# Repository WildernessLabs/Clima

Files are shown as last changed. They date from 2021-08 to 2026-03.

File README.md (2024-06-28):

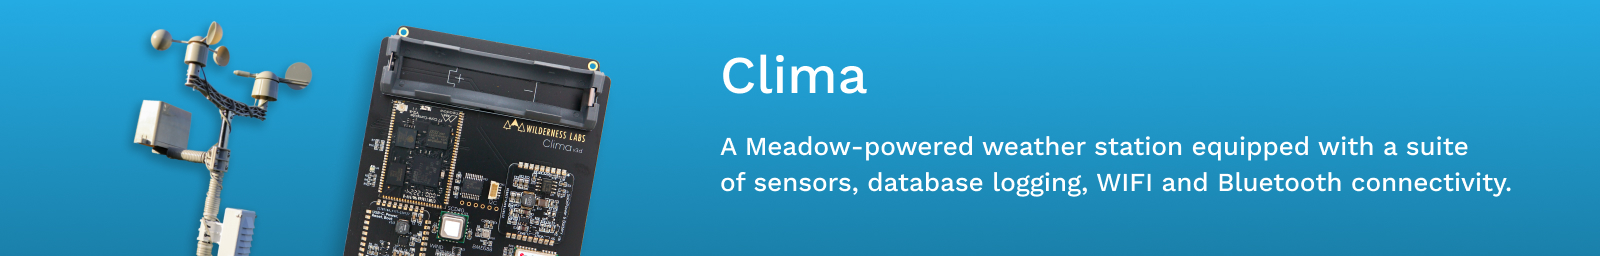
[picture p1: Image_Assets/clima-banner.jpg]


Clima is a solar-powered, custom embedded-IoT solution that tracks climate from a suite of sensors, saves data locally for access via Bluetooth, uses a RESTful Web API, and synchronizes data to the cloud.

## Contents
* [Clima Pro](#clima)
* [Assembly Instructions](#assembly-instructions)
* [Getting Started](#getting-started)
* [Hardware Specifications](#hardware-specifications)
* [Support](#support)

## Clima

With this kit, it includes the complete package of sensors, PCB enclosure and mount to place this outdoors. You'll be able to measure wind speed/direction, rain volume, atmospheric conditions like temperature, pressure, humidity, CO2 levels and GPS Coordinates.

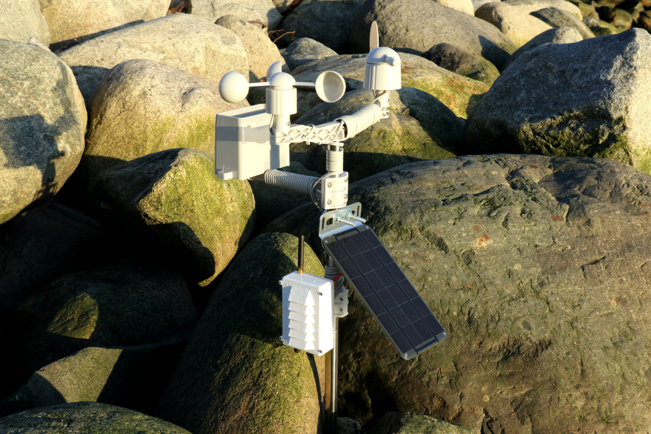
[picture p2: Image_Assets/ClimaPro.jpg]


## Assembly Instructions

A complete kit of Clima.Pro can be found on the [Wilderness Labs Store](https://store.wildernesslabs.co/collections/frontpage/products/clima-weather-station-kit) and the Instructions for assembly can be found [here](/Docs/Clima.Pro/Assembly_Instructions/readme.md).

The store version is 100% kit complete, including the option to upgrade the PCB, Enclosure and Battery only, if you include a previous version of the kit.

You can also source all of the components yourself. For a list of components see the [Clima Pro Bill of Material (BoM)](/Docs/Clima.Pro/Bill_of_Materials.md)

## Getting Started

To simplify the way to use this Meadow-powered reference IoT product, we've created a NuGet package that instantiates and encapsulates the onboard hardware into a `Clima` class.

1. Add the ProjectLab Nuget package your project: 
    - `dotnet add package Meadow.Clima`, or
    - [Meadow.Clima Nuget Package](https://www.nuget.org/packages/Meadow.Clima/)

2. Change the App type on your MeadowApp class to `ClimaAppBase` and initialize Clima's `MainController` passing the `Hardware` and a `INetworkAdapter` such as your WiFi adapter onboard the Meadow Core Compute Module:  

```csharp
public class ClimaApp : ClimaAppBase
{
    public override Task Initialize()
    {
        Resolver.Log.Info($"Initialize...");

        var mainController = new MainController();

        var wifi = Hardware.ComputeModule.NetworkAdapters.Primary<IWiFiNetworkAdapter>();

        mainController.Initialize(
            hardware: Hardware,
            networkAdapter: wifi);
            .
            .
            .
```

3. Run the [Clima_Demo](Source/Clima_Demo/) project that does periodic readings of all its sensors and sends them to [Meadow.Cloud](https://www.meadowcloud.co) if you have a Wilderness Labs account and have provisioned your device.

## Hardware Specifications

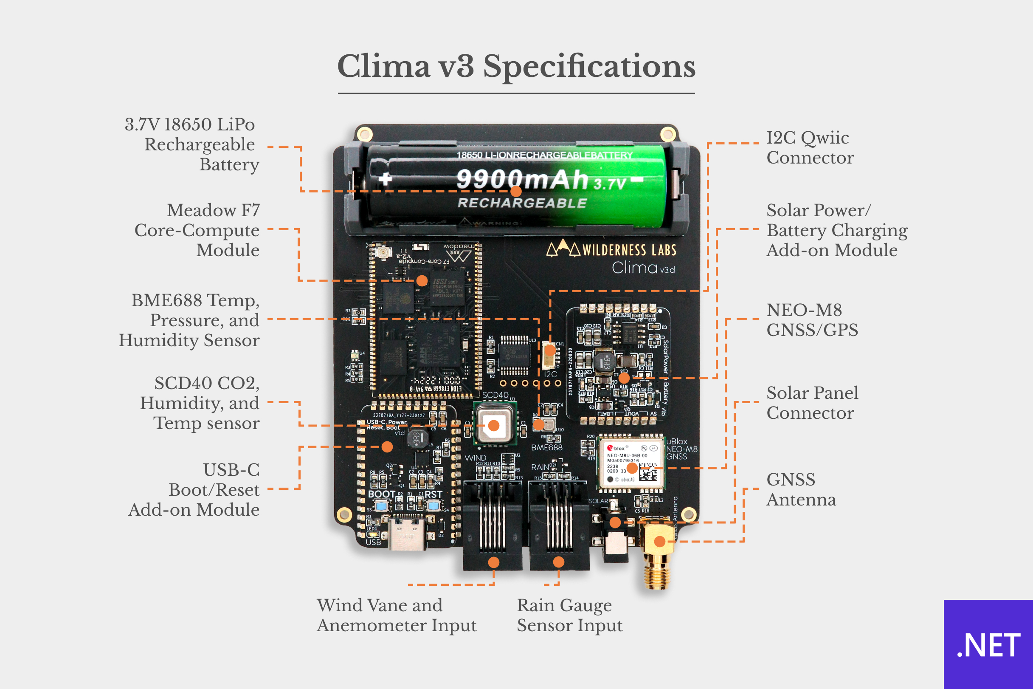
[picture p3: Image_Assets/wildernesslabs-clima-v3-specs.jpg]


You can find the schematics and other design files in the [Hardware_Design folder](Hardware_Design/).

## Support

Having trouble building/running these projects? 
* File an [issue](https://github.com/WildernessLabs/Meadow.Desktop.Samples/issues) with a repro case to investigate, and/or
* Join our [public Slack](http://slackinvite.wildernesslabs.co/), where we have an awesome community helping, sharing and building amazing things using Meadow.

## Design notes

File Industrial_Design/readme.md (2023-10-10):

# Industrial Design

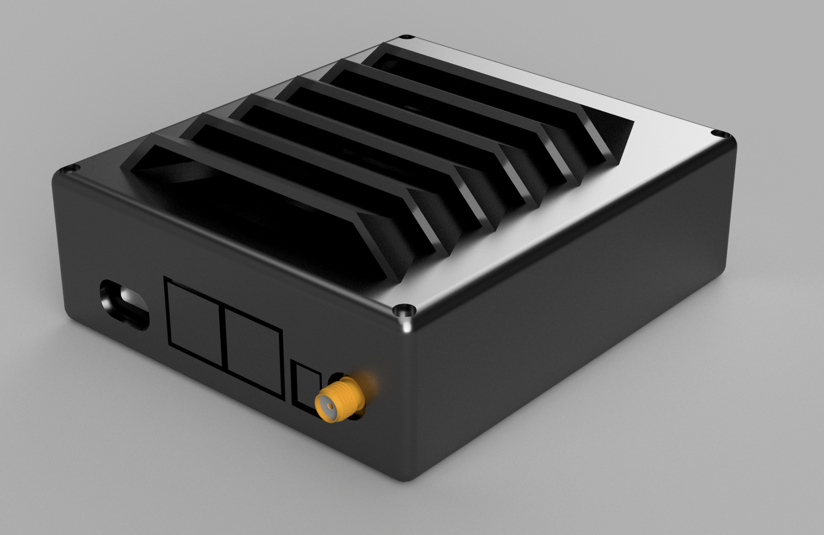
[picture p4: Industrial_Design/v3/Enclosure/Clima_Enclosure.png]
Rendering of the Clima enclosure.


Clima.Pro uses a 3D-Printable enclosure that holds the Meadow board and the custom Clima PCB. 

The enclosure was designed used AutoDesk Fusion 360, and if you want to customize it, you can find the design source in the source folders:
 * [V1](v1/Enclosure/Source)
 * [v3](v3/Enclosure/Source)

The STL files can be found in the `STLs_for_Printing` folder
 * [V1](v1/Enclosure/STLs_for_Printing)
 * [V3](v3/Enclosure/STLs_for_Printing)

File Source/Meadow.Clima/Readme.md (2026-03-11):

# Meadow.Clima

**Library for the Meadow Clima IoT weather station accelerator**

The **Clima** library is included in the **Meadow.Clima** nuget package and is designed for the [Wilderness Labs](www.wildernesslabs.co) Meadow .NET IoT platform.

Clima is a solar-powered, custom embedded-IoT solution that tracks climate from a suite of sensors, saves data locally, and synchronizes telemetry to Meadow.Cloud.

For more information on developing for Meadow, visit [developer.wildernesslabs.co](http://developer.wildernesslabs.co/).

To view all Wilderness Labs open-source projects, including samples, visit [github.com/wildernesslabs](https://github.com/wildernesslabs/).

## Onboard Hardware

| Peripheral | Description |
|---|---|
| NEO-M8 | GNSS/GPS module |
| BME688 | Temperature, pressure, humidity, and gas resistance sensor |
| SCD40 | CO2, humidity, and temperature sensor |
| SwitchingAnemometer | Wind speed sensor |
| WindVane | Wind direction sensor |
| SwitchingRainGauge | Rain accumulation sensor |
| RGB LED | Onboard status indicator |
| Solar input | Solar charging with battery voltage monitoring |

## Installation

You can install the library from within Visual Studio using the NuGet Package Manager or from the command line using the .NET CLI:

`dotnet add package Meadow.Clima`

## Usage

```csharp
public class ClimaApp : ClimaAppBase
{
    public override Task Initialize()
    {
        Resolver.Log.Info("Initialize...");

        var mainController = new MainController();

        var wifi = Hardware.ComputeModule.NetworkAdapters.Primary<IWiFiNetworkAdapter>();

        mainController.Initialize(
            hardware: Hardware,
            networkAdapter: wifi);

        return base.Initialize();
    }

    public override Task Run()
    {
        return base.Run();
    }
}
```

For lower-level hardware access, you can use `ClimaHardwareProvider` directly:

```csharp
public class MeadowApp : App<F7CoreComputeV2>
{
    IClimaHardware clima;

    public override Task Initialize()
    {
        clima = ClimaHardwareProvider.Create();

        if (clima.TemperatureSensor is { } tempSensor)
        {
            tempSensor.Updated += (s, e) =>
                Resolver.Log.Info($"Temperature: {e.New.Celsius:N1}C");
        }

        if (clima.Anemometer is { } anemometer)
        {
            anemometer.Updated += (s, e) =>
                Resolver.Log.Info($"Wind speed: {e.New.KilometersPerHour:N1} km/h");
        }

        if (clima.Gnss is { } gnss)
        {
            gnss.GnssDataReceived += (s, e) =>
                Resolver.Log.Info($"GNSS data received");
        }

        return Task.CompletedTask;
    }

    public override async Task Run()
    {
        if (clima.TemperatureSensor is { } tempSensor)
            tempSensor.StartUpdating(TimeSpan.FromMinutes(1));

        if (clima.Anemometer is { } anemometer)
            anemometer.StartUpdating(TimeSpan.FromSeconds(15));

        if (clima.Gnss is { } gnss)
            gnss.StartUpdating();

        await Task.Delay(Timeout.Infinite);
    }
}
```

## How to Contribute

- **Found a bug?** [Report an issue](https://github.com/WildernessLabs/Meadow_Issues/issues)
- Have a **feature idea or driver request?** [Open a new feature request](https://github.com/WildernessLabs/Meadow_Issues/issues)
- Want to **contribute code?** Fork the [Clima](https://github.com/WildernessLabs/Clima) repository and submit a pull request against the `develop` branch

## Need Help?

If you have questions or need assistance, please join the Wilderness Labs [community on Slack](http://slackinvite.wildernesslabs.co/).

## About Meadow

Meadow is a complete, IoT platform with defense-grade security that runs full .NET applications on embeddable microcontrollers and Linux single-board computers including Raspberry Pi and NVIDIA Jetson.

### Build

Use the full .NET platform and tooling such as Visual Studio and plug-and-play hardware drivers to painlessly build IoT solutions.

### Connect

Utilize native support for WiFi, Ethernet, and Cellular connectivity to send sensor data to the Cloud and remotely control your peripherals.

### Deploy

Instantly deploy and manage your fleet in the cloud for OtA, health-monitoring, logs, command + control, and enterprise backend integrations.

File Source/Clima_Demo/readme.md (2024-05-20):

```mermaid
flowchart TD
%% Nodes
    A("Boot")
    B{"Connect to Cloud"}
    C("Deliver Data")
    D("Shutdown network")
    E("Device Sleep")
    F("Device Wake")
    G("Collect Telemetry")
    H{{"`tick++ % pubcount`"}}

    ne_0("== 0")
    eq_0("!= 0")

%% Edge connections between nodes
    A --> B
    B --> yes --> C
    B --> no --> E
    C --> D
    D --> E
    E -.-> F
    F --> G
    G --> H
    H --> eq_0 --> E
    H --> ne_0 --> B
```

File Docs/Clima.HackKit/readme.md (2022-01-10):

# Clima Hack Kit Circuit

With an LM35 Analog Temperature sensor, a TFT SPI ST7789 display and three push buttons (all included in the Hack Kit), wire your board like the following Fritzing Diagram:

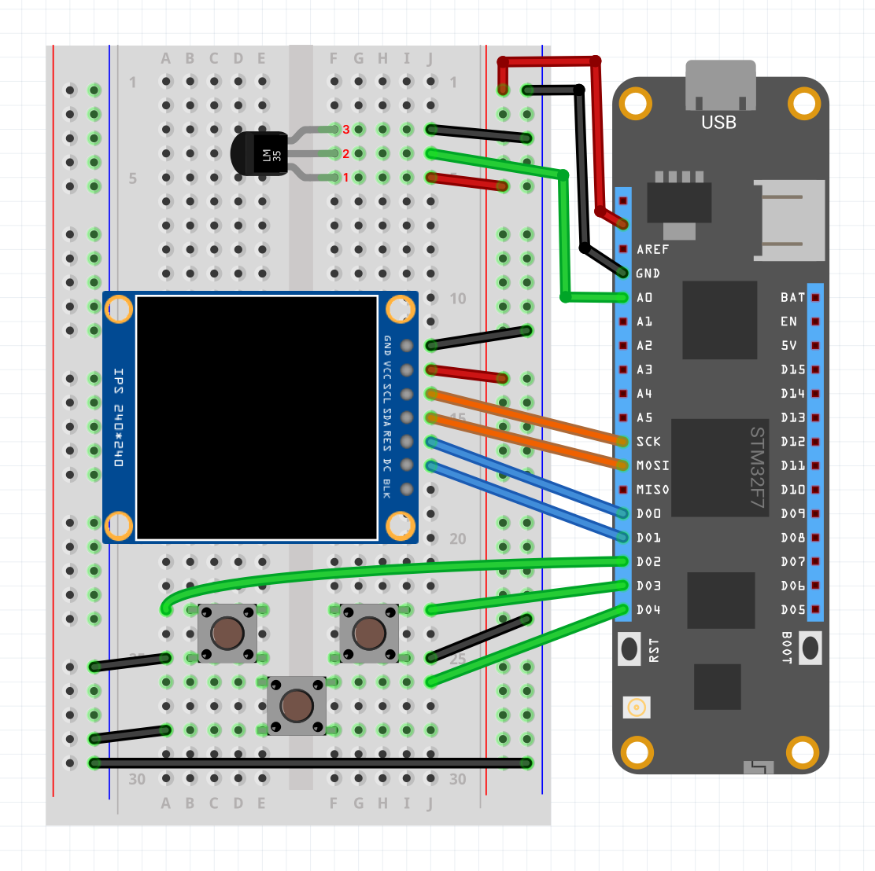
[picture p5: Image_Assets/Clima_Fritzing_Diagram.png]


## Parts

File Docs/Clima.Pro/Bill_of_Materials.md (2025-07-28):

# Clima.Pro Bill of Materials (BoM)

Complete Clima.Pro kits can be purchased at the [Wilderness Labs Store](https://store.wildernesslabs.co/collections/frontpage/products/clima-weather-station-kit), or you can source the components yourself. The Clima.Pro BoM is listed below:

| Qty | Item | Cost/MSRP (approx.) |
|-----|---|---|
| 1 | [Shenzen Fine-Offset Electronics Weather Sensor Kit](https://www.sparkfun.com/products/15901) | $ 79.95 |
| 1 |	Clima PCB (see below) | ~$ 25.00 | 
| 1 | 3d Printed Enclosure and Pipe Mount (see below) | $ 3.00 |
| 1 | [18650 LiIon Battery](https://www.amazon.com/s?k=18650+battery) | $ 5.00 |
| 8 | [M3 Heat Inserts](https://www.amazon.com/gp/product/B087NBYF65) | $ 5.00 |
| 8 | [M3x12 Hex Head Screws](https://www.amazon.com/gp/product/B01LZPZL3W) | $ 5.00 | 
| 4 | [M2x3 Heat-Set Inserts](https://www.amazon.com/gp/product/B07LBRL93N/) | $ 1.00 |
| 8 | [M2x6 bolts (4 for lid, 4 for board)](https://www.amazon.com/Hilitchi-420pcs-Stainless-Socket-Assortment/dp/B014OO5KQG) | $ 1.00 |
| 1 | [3.5 Watt, 6V Solar Panel](https://voltaicsystems.com/3-5-watt-panel/) | $ 30.00 |
| 1 | [Solar Panel Bracket](https://voltaicsystems.com/small-bracket/) | $ 6.00 |
| 1 | [U-Bolt With Mounting Plate, 1/4"-20 Thread Size, 1" Id](https://www.mcmaster.com/catalog/127/1720/) | $ 2.00 |
| 1 | [Antenna - 2dBi SMA Plug](https://octopart.com/ant-2whip2-sma-rf+solutions-87213220?r=sp) | $ 3.50 |
| 1	  | [SMA to uFL/u.FL/IPX/IPEX RF Adapter Cable](https://www.adafruit.com/product/851) | $ 4.00 |

## 3D Printed Enclosure

The enclosure can be 3D printed, but should be printed using PETG or some other UV-Resistant material. PLA will degrade quickly in the sun. Additionally, it should be a light color such as white to avoid passive solar radiation absorption which will interfere with the temperature and humidity readings. We use the [Duramic 3D Silk White](https://www.amazon.com/gp/product/B07TRPQ4MN) filament.

If you're printing the enclosure yourself, you'll also need a [soldering iron](https://www.amazon.com/dp/B00B3SG6UQ) and [heat-set insert tips](https://www.amazon.com/dp/B08B17VQLD) to install the heat-set inserts.

All of the enclosure files can be found in the [/Industrial_Design folder](/Industrial_Design/).

## Clima.Pro PCB

The Clima.Pro PCB was created in EasyEDA, and the source files as well as component BoM can be found on [OSHW Lab](https://oshwlab.com/bryan_6020/wilderness-labs-clima).

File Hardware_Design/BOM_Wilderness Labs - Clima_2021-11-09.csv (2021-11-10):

ID | Name | Designator | Footprint | Quantity | Manufacturer Part | Manufacturer | Supplier | Supplier Part | Price
1 | 0.1u | C1,C2,C3 | C0603 | 3 | CC0603KRX7R9BB103 | Yageo
2 | 47pF | C4 | C0603 | 1 | CC0603JRNPO9BN470 | Yageo
3 | BAS70FILM | D1 | SOT23-3 | 1 | BAS70FILM | STMicroelectronics | LCSC | C233387 | 0.133
4 | BAS70-04FILM | D2 | SOT-23-3_L2.9-W1.3-P1.90-LS2.4-BR | 1 | BAS70-04FILM | STMicroelectronics | LCSC | C283251 | 1.046
5 | NEO-M8U-0 | IC1 | NEO-M8U | 1
6 | PJ-002AH-SMT-TR | J2 | CUI_PJ-002AH-SMT-TR | 1
7 | 1kΩ | L1 | L0402 | 1 | BLM15HD102SN1D | MuRata | LCSC | C21516 | 0.007
8 | 4.7kΩ | R1,R2,R13 | R0603 | 3 | RC0603FR-074K7L | Yageo
9 | 220 | R3,R4 | R0603 | 2 | RC0603FR-07220RL | Yageo
10 | 10k | R5,R6,R8 | R0603 | 3 | RC0603FR-0710KL | Yageo
11 | 10 | R7 | R0603 | 1 | RC0603FR-0710RL | Yageo
12 | 1k | R9,R10,R11,R12,R14,R15,R16 | R0603 | 7 | RC0603FR-071KL | Yageo
13 | 680 | R17 | R0603 | 1 | RC0603FR-07680RL | Yageo
14 | 1909763-1 | RF1 | ANT-SMD_1909763-1 | 1 | 1909763-1 | TE Connectivity | LCSC | C392444 | 0.208
15 | 5555165-1 | RJ1-WIND,RJ2-RAIN | RJ11-TH_6P-P2.54-S2.54_L18.3-W13.4-EH10.2 | 2 | 5555165-1 | TE Connectivity | LCSC | C305981 | 0.725
16 | Meadow F7 Micro Dev Board | U1 | MEADOWF7MICRO_HEADERS_ONLY | 1 | MEDF7DEV | Wilderness Labs | Mouser | 977-MEADOWF7MICRO
17 | BAV99DWQ-7-F | U2 | SOT363 (NO POLARITY) | 1 | BAV99DWQ | Diodes Incorporated | Digi-Key | BAV99DWQ-7-FDITR-ND
18 | 2200mAh Battery Holder | U3 | 2200MAH_BATTERY_HOLDER | 1
19 | BME680 | U4 | LGA-8_L3.0-W3.0-P0.80-TR | 1 | BME680 | Bosch Sensortec | LCSC | C125972 | 16.526

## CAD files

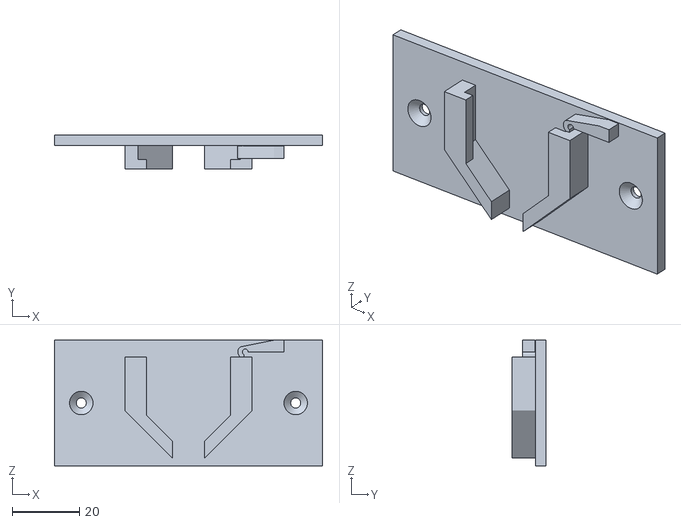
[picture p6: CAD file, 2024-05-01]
Industrial_Design/v4/clima4-cleat-f.stl
80.0 x 10.0 x 37.5

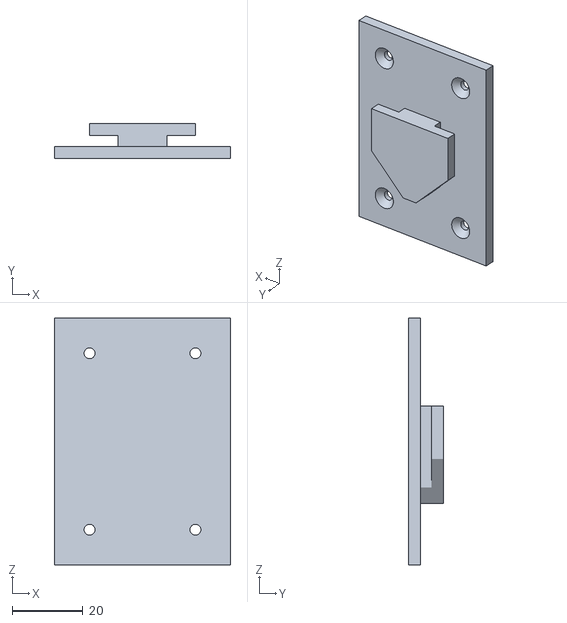
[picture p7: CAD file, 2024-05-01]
Industrial_Design/v4/clima4-cleat-m.stl
50.0 x 10.0 x 70.0

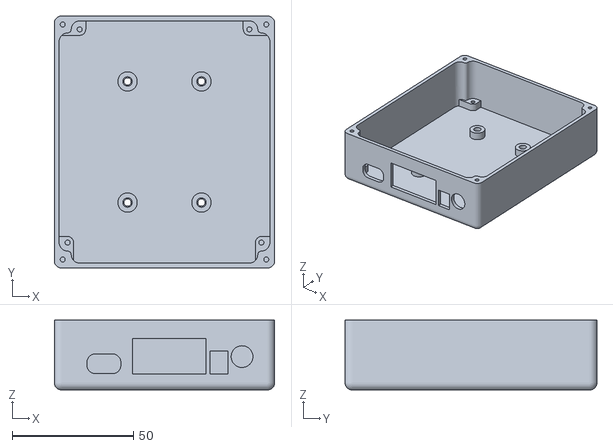
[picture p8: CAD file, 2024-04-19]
Industrial_Design/v4/Clima4_Enclosure_Bottom.stl
91.0 x 104.0 x 28.9

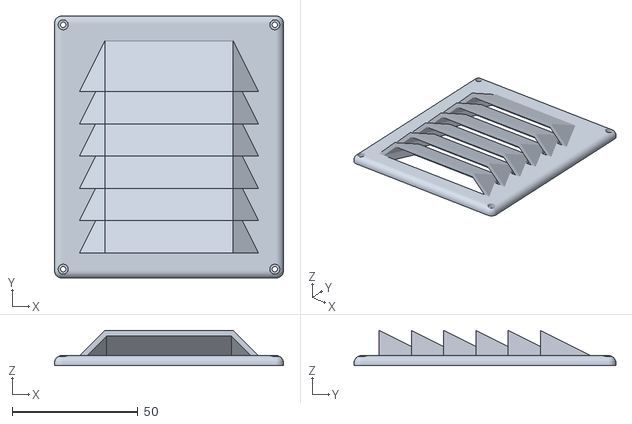
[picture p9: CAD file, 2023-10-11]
Industrial_Design/v4/Clima4_Enclosure_Top.stl
91.0 x 104.0 x 14.0

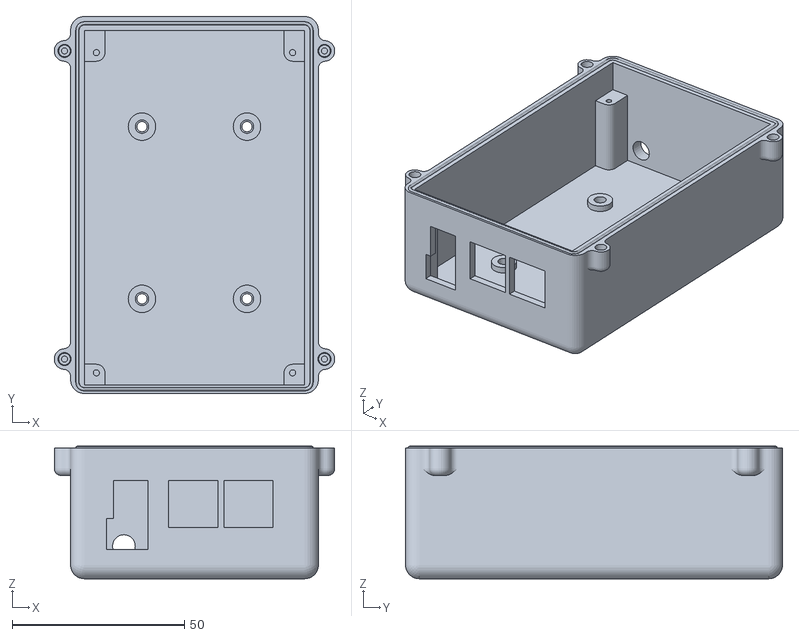
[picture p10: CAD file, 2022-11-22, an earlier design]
Industrial_Design/v1/Enclosure/STLs_for_Printing/Clima_Enclosure_Bottom.stl
81.5 x 109.5 x 38.5

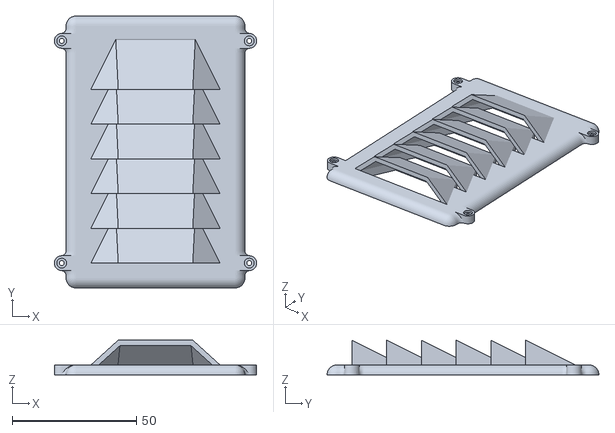
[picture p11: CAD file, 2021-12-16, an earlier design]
Industrial_Design/v1/Enclosure/STLs_for_Printing/Clima_Enclosure_Top.stl
81.5 x 109.5 x 14.0

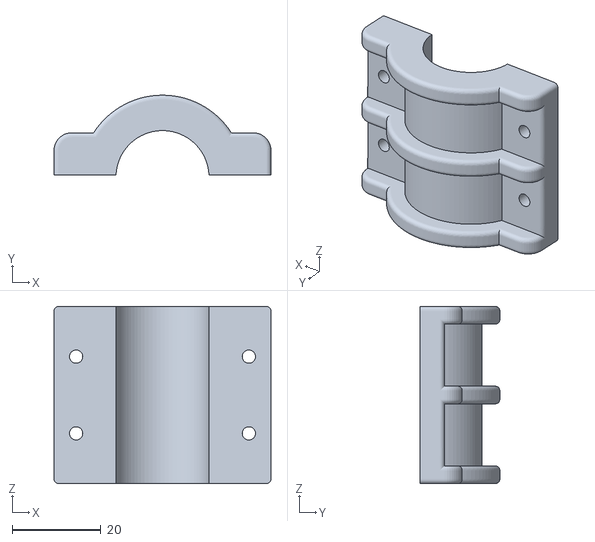
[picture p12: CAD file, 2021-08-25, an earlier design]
Industrial_Design/v3/Enclosure/STLs_for_Printing/Pipe_Mount_Clamp_Closure_Side.stl
49.0 x 18.0 x 40.0

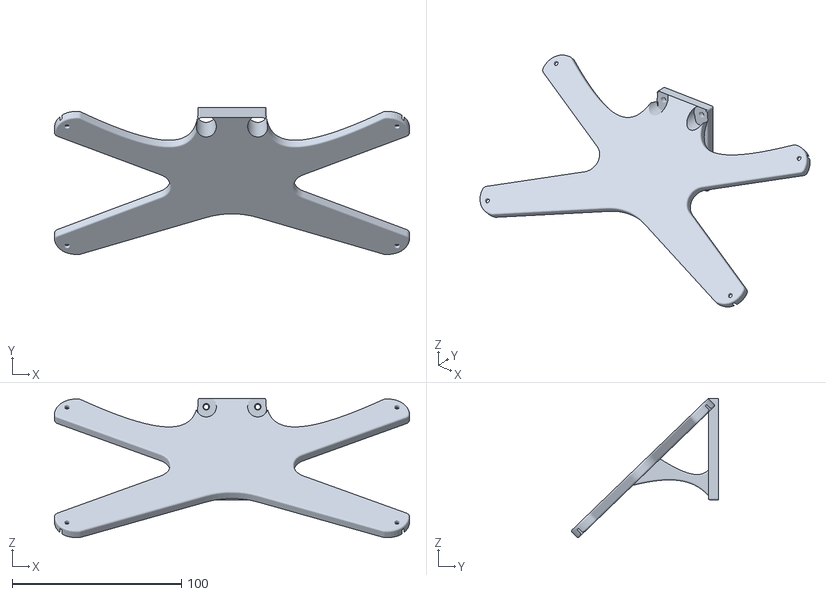
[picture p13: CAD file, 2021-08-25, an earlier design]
Industrial_Design/v1/Enclosure/STLs_for_Printing/Pipe_Mount_Solar_Adapter.stl
210.0 x 86.9 x 82.4

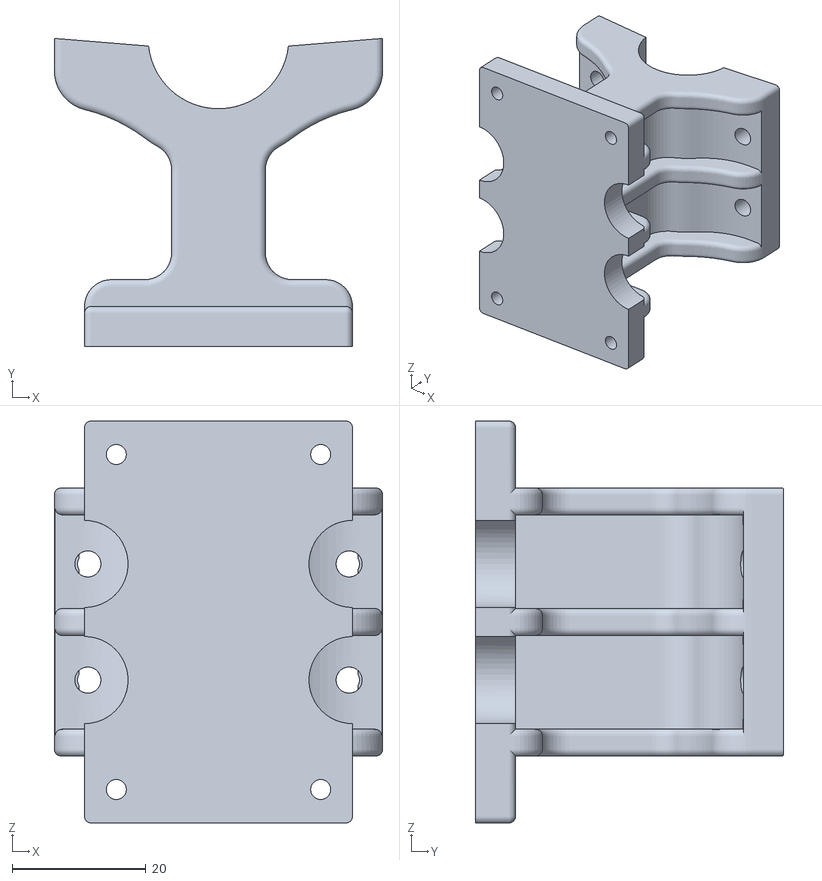
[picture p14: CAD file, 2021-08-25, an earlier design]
Industrial_Design/v3/Enclosure/STLs_for_Printing/Pipe_Mount_Enclosure_Side.stl
49.0 x 46.0 x 60.0

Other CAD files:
Industrial_Design/v3/Enclosure/STLs_for_Printing/CL_Enclosure_Bottom.stl
Industrial_Design/v1/Enclosure/Source/Clima.Pro Enclosure.f3d
Industrial_Design/v1/Enclosure/Source/Clima_Clamp.f3d
Industrial_Design/v3/Enclosure/Source/Clima v3 Enclosure.f3z
Industrial_Design/v3/Enclosure/Source/Clima_Clamp.f3d

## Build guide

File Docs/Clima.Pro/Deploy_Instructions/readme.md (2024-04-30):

## Clima.Pro Application Deployment

### Step 1. - Prepare Dev Environment

 * **Download and install [Visual Studio](https://visualstudio.microsoft.com/) or [Visual Studio Code](https://code.visualstudio.com/)** - For either Windows or macOS. Community edition will work fine.

 * **Follow the [Meadow.OS Deployment Guide](http://developer.wildernesslabs.co/Meadow/Getting_Started/Deploying_Meadow/)**:
   * The above guide should show you how to install `Meadow.CLI`
   * Walk your through out to download the latest Meadow.OS and flash it to the Clima Meadow board.

 * **Follow the [`Hello, Meadow` Guide](http://developer.wildernesslabs.co/Meadow/Getting_Started/Hello_World/)**:
   * The above guid should show  you to Install the Visual Studio and VSCode Extension(s) for Meadow.

### Expected Development version stack (RC-1)
At this point, you should have the following versions on your development machine
* Meadow.CLI - `v2.x`
* Visual Studio
  * MacOS - `v1.9.x`
  * Windows - `v1.9.x`
* VS Code - `v1.9.x`

* Meadow

And if you run this command line: `meadow device info`, you should see something similar to:
  ```
  Meadow by Wilderness Labs
  Board Information 
      Model: F7Micro
      Hardware version: F7CoreComputeV2
      Device name: MeadowF7

  Hardware Information 
      Processor type: STM32F777IIK6
      ID: [Specific ID for your Meadow]
      Serial number: [Specific Serial No. for your Meadow]
      Coprocessor type: ESP32
      MAC Address - 
    WiFi: [Specific Mac Address for your Meadow]

  Firmware Versions 
      OS: 1.10.0.2
      Runtime: 1.10.0.2
      Coprocessor: 1.10.0.1
      Protocol: 8
  ```

### Step 2. - Deploy the Clima App

 **Clone the Clima Repo**:
 
 [Clone](https://docs.github.com/en/desktop/contributing-and-collaborating-using-github-desktop/adding-and-cloning-repositories/cloning-and-forking-repositories-from-github-d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) the [Clima(this) repository](https://github.com/wildernesslabs/Clima) locally.

 **Open the Clima VS Solution**:

 With either Visual Studio or VSCode running, navigate to the `source` folder and open the `Meadow.Clima.sln`. 

 **Add WiFi Credentials**:
 
 Edit the `secrets.cs` file to have the correct credentials for the WiFi your Clima will connect to.

 **Deploy the MeadowClimaProKit App**

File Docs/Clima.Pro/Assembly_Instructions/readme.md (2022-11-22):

## Clima.Pro Assembly Instructions



* **[Part 1 - 3D Printed Enclosure Assembly](Enclosure_Assembly/readme.md)** - Skip this step unless you're printing at home.
* **[Part 2 - Electronics Installation](Electronics_Installation/readme.md)** - Installing the PCB, antenna, etc., into the enclosure.
* **[Part 3 - Sensor Assembly](Weather_Sensors/readme.md)** - Assembling the weather gauges and pole.
* **[Part 4 - Enclosure Mounting](Enclosure_Mounting/readme.md)** - Mounting the enclosure to the sensor pole.
* **[Part 5 - Solar Panel Installation](Solar_Panel_Installation/readme.md)** - Installing the solar panel.

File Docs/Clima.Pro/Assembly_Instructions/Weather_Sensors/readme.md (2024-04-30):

# Weather Sensors Assembly

To assemble the whole Clima kit with all it's sensors, you'll need the set of 3 long screws with it's bolts, and 2 smaller screws. They should be in a little zip lock bag like this:

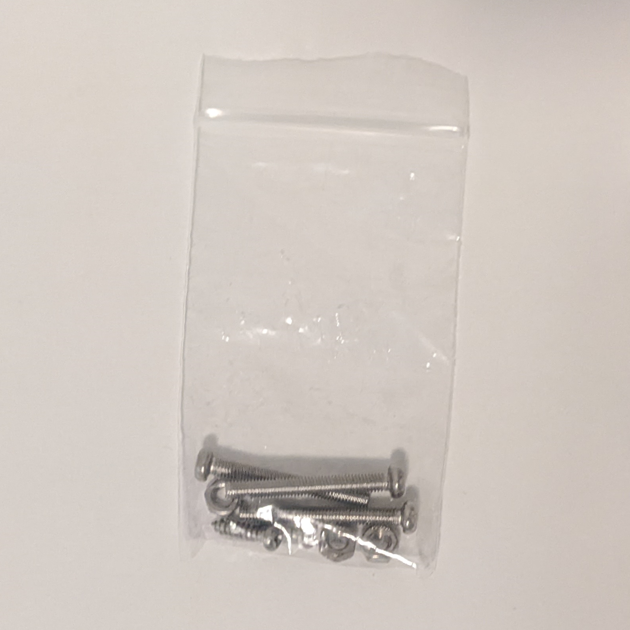
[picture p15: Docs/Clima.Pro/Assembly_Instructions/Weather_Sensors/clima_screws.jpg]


## Assembling

Start by connecting the two steel tubes together like so:



Next, one of the tube ends has a small rounded gap and a hole right below it. In that end, place the sensor support for the wind vane and anemometer. Use one of the long screws and bolts to fix the support to the tube.



On the right end of the support piece you can put the anemometer. It has three possible positions to connect it to the base, keep rotating it until you see the the hole to insert another long screw and bolt to secure it to the support. You can thread the 

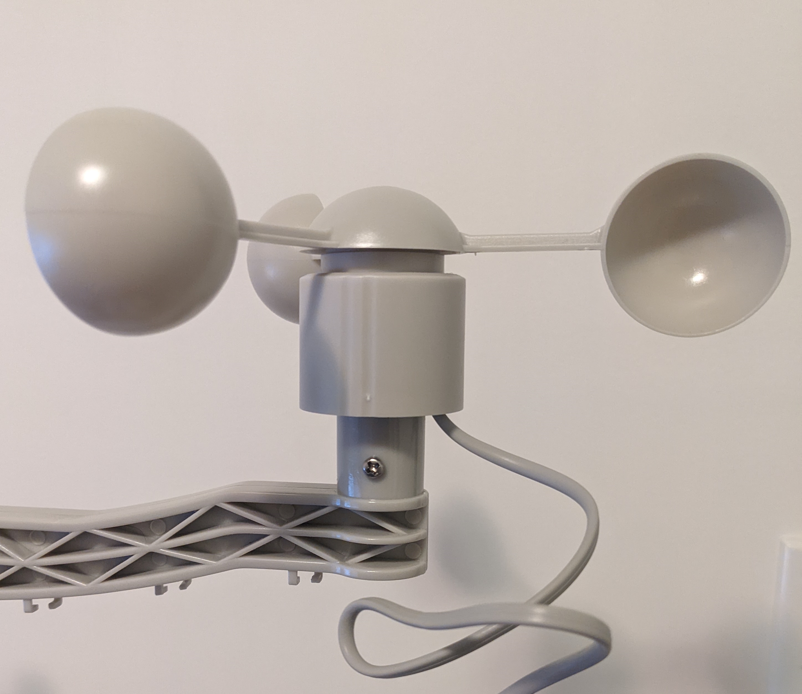
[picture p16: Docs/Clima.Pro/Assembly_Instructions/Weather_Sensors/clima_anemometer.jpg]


On the left side of the support you can place the wind vane. Like we did with the anemometer, make sure to position it correctly to use the third and final screw and bolt to secure the sensor to the support.



Take the short cable from the anemometer and carefully feed/clip it through the provided cable tidies until it reaches the wind vane.

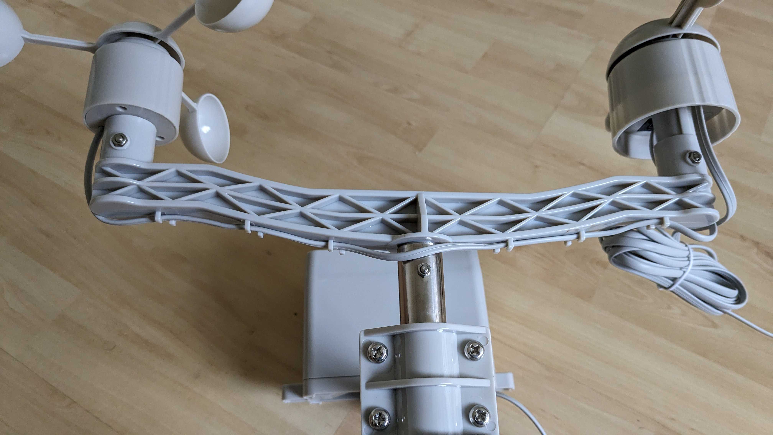
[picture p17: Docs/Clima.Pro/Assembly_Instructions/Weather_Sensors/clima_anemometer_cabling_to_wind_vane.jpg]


Under the wind vane you can see a small connection port. Connect the end of the anemometer into the wind vane port underneath.

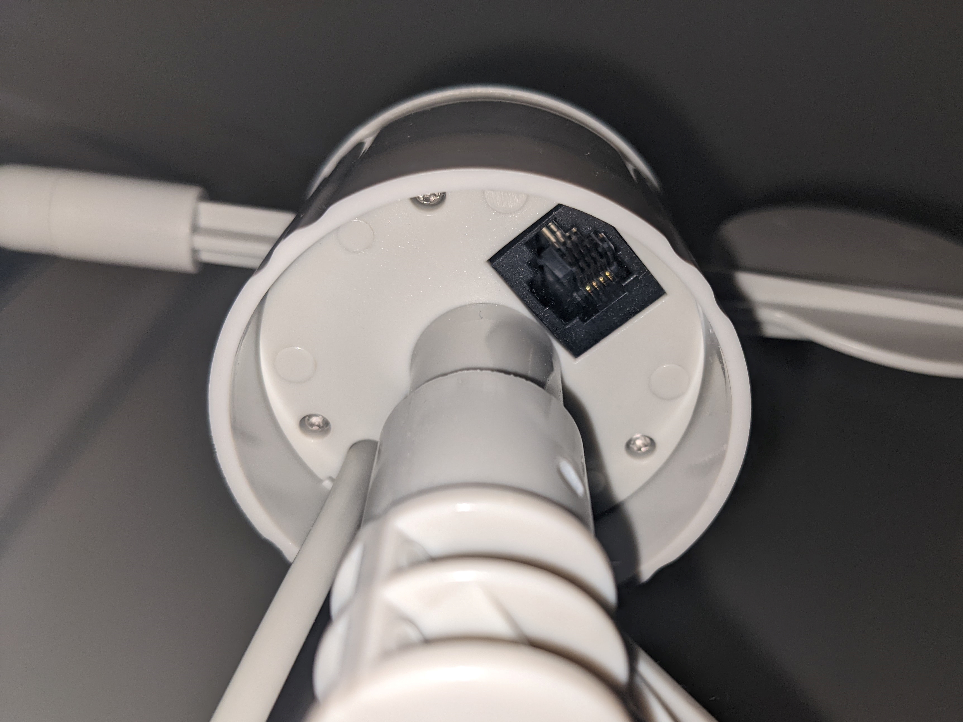
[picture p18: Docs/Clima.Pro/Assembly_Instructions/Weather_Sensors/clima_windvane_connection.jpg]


At this point, you should have something like this:

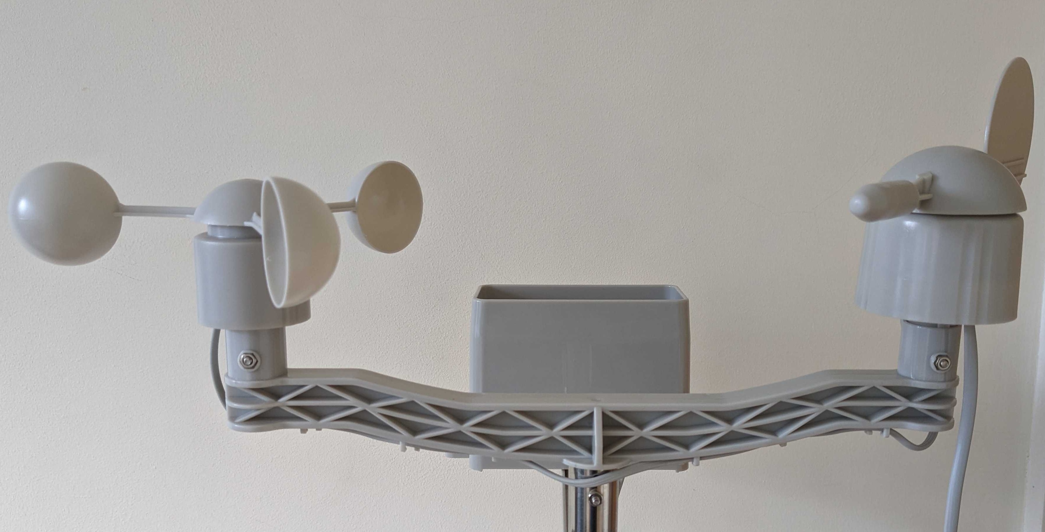
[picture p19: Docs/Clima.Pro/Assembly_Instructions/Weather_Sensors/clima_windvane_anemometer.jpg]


About an inch/2.54cm below the tube end, where the support piece is, use the rain meter support piece and secure it onto the tube, making sure it is perpendicular to the other two sensors.

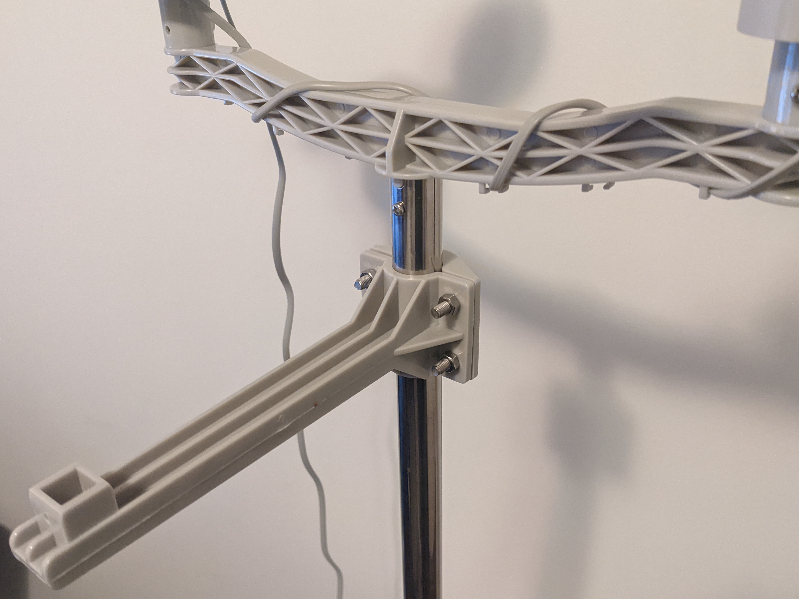
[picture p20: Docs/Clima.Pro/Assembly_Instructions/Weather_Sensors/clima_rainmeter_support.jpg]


Take the rain meter and place it on the support piece and secure it with the last two small screws: one goes in the bottom and the other on one of the sides: 

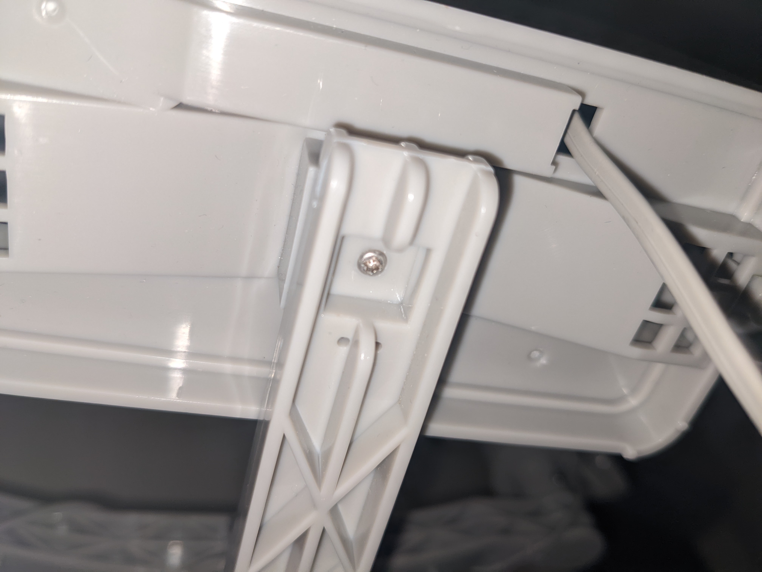
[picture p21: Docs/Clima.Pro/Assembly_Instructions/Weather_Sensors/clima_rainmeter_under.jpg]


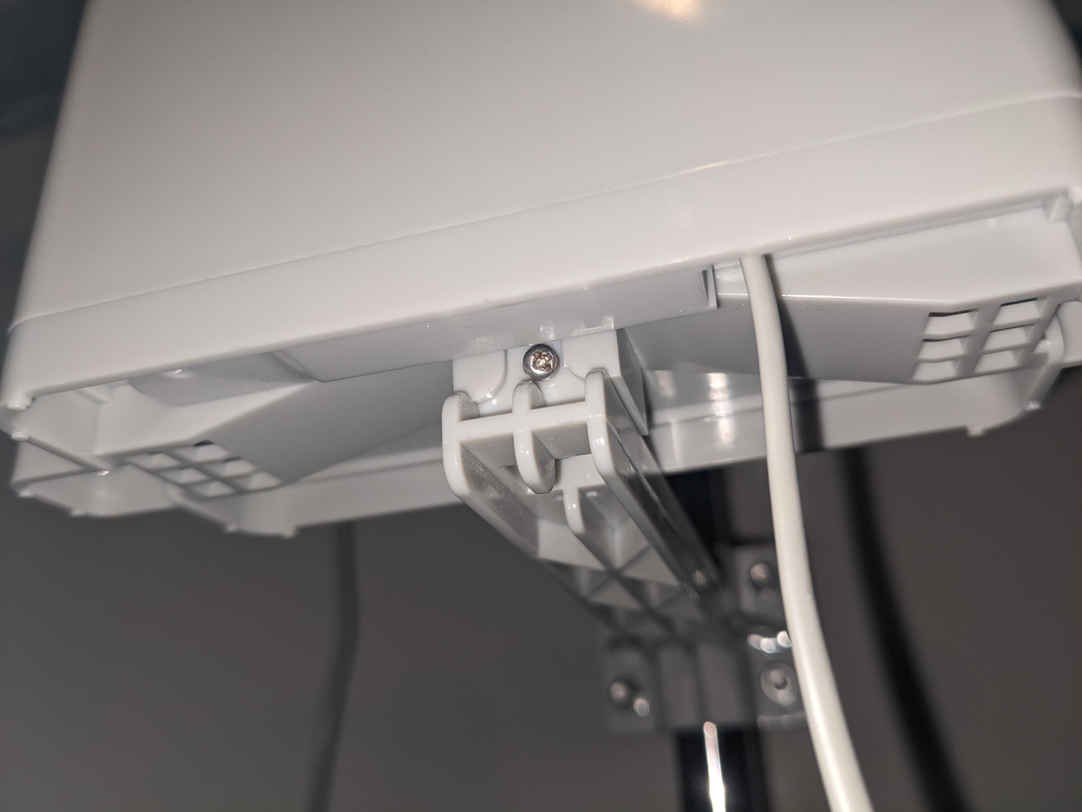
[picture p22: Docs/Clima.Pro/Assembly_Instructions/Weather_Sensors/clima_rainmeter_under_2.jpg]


About one inch/2.54cm above where the 2 steel tubes connect, mount the Clima Meadow module onto the tube.

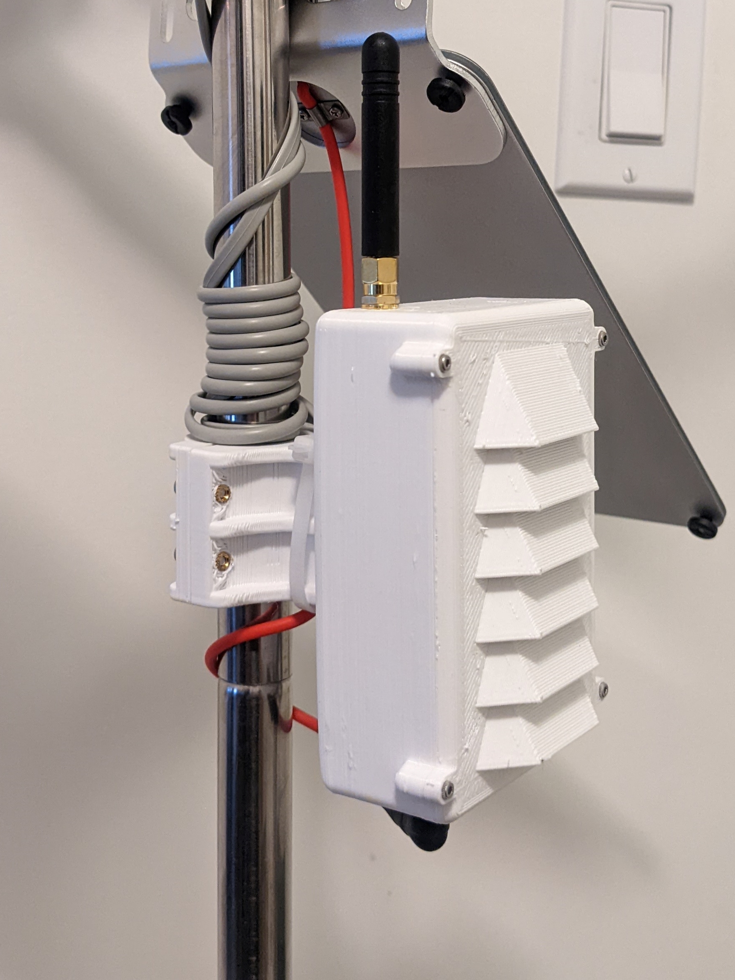
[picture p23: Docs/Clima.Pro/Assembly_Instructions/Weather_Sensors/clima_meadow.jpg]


Now you can connect the rain meter sensor in the middle port and the wind sensor on the other connector available. The round port is used for the solar panel. 

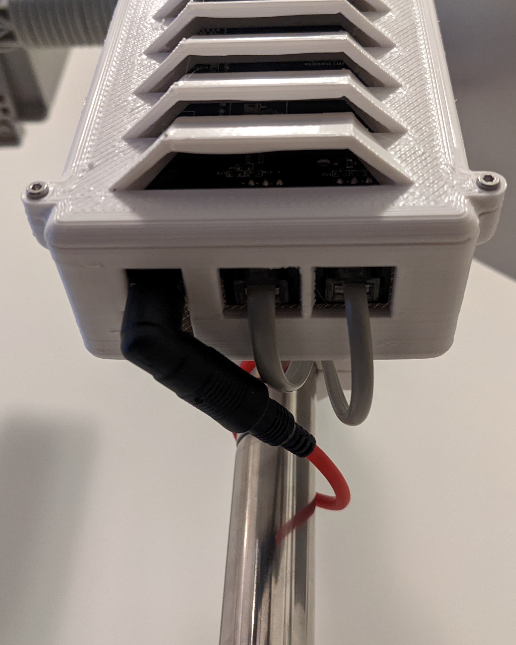
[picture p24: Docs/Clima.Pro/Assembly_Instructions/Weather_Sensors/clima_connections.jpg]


Additionally, you can tidy the cable of the wind sensors by looping it around its support piece and/or tubes, making your way to the Meadow module.



You can do the same with the rain meter sensor's cable, looping it around its support piece, making your way to the Meadow enclosure.

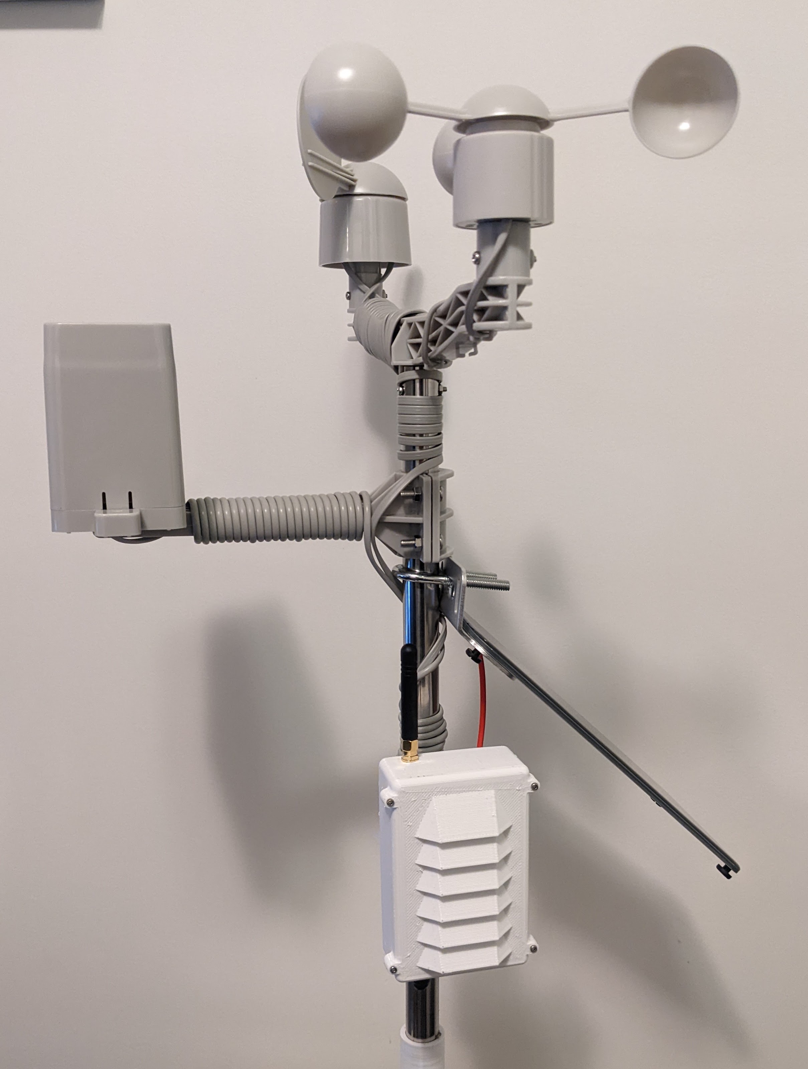
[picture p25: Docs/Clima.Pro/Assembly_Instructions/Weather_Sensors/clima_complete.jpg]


## [Next - Enclosure Assembly](../Enclosure_Assembly/readme.md)

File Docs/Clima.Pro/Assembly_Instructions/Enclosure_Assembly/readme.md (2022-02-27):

# Clima.Pro 3D Printed Enclosure Assembly

If you've ordered the enclosure from the Wilderness Labs store, it already comes assembled with the heat-set inserts in it, so you can skip this step and go directly to [Electronics Installation instructions](../Electronics_Installation/readme.md).

However, if you're 3D printing at home, you'll need to follow the instructions below:

## Post-process 3D Print

Stringing and burrs are a by-product of printing with PETG and are mostly cosmetic, but can easily be cleaned off with a box-cutter knife, razor blade, or similar.

## Install M3 Heat-Set Inserts into Enclosure Body

Install a heat-set insert tool into your soldering iron, plug it in and turn it on. After a couple of minutes it should be hot enough. Place an M3 heat-set insert onto the end of the tool, being careful not to touch the hot tip:



Then, while holding the enclosure, guide the insert into one of the holes until it's just flush with the top of the hole:



Repeat this for all four heat set inserts on the main enclosure body.

## Plunge Excess Plastic from Heat-Set Inserts

Install an M3 bolt through the M3 insert from the inside of the enclosure, to push any plastic that might have melted into the insert:



Screw the bolt far enough that it pokes out the other side of the insert and pushes out the plastic:



Remove the bolt and repeat for the remaining M3 inserts.

Once all four have been plungd, using a knife, trim the excess plastic:



## Install the M3 Heat-Set Inserts into the Enclosure Mount

Using the same method, install (4), M3 inserts into the enclosure mount from the backside, and then push excess plastic out with a bolt and trim:



## Install the M2 Heat-Set Inserts into the Enclosure Body

Finally, install the M2 heat-set inserts for the lid into the enclosure body:



## [Next - Electronics Installation](../Electronics_Installation/readme.md)

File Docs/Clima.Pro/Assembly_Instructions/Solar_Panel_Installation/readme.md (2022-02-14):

# Solar Panel Installation

## Solar Panel Mount

Using the U-bolt bracket, attach the solar panel mount to the pole:

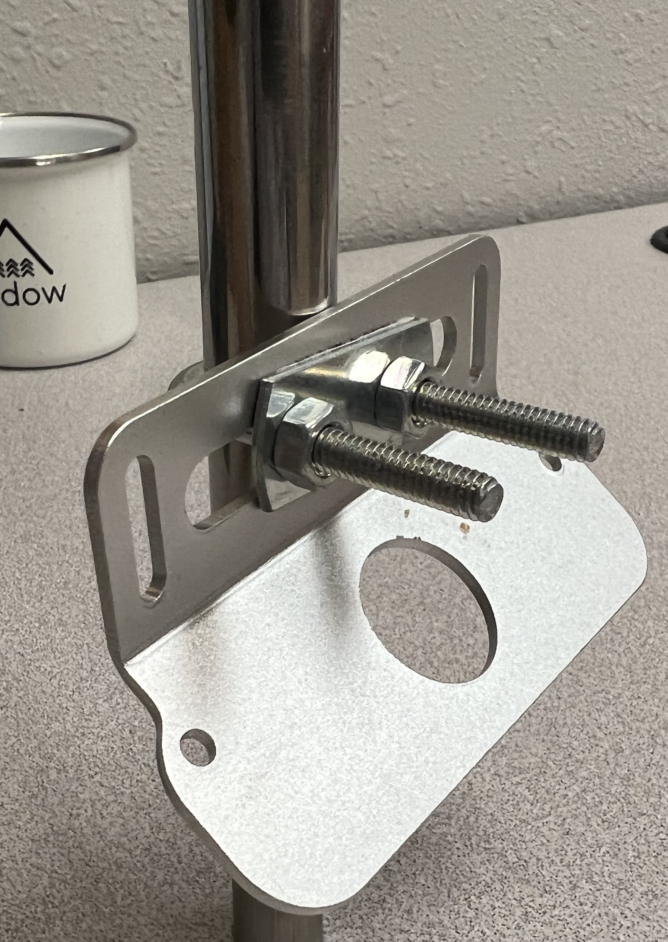
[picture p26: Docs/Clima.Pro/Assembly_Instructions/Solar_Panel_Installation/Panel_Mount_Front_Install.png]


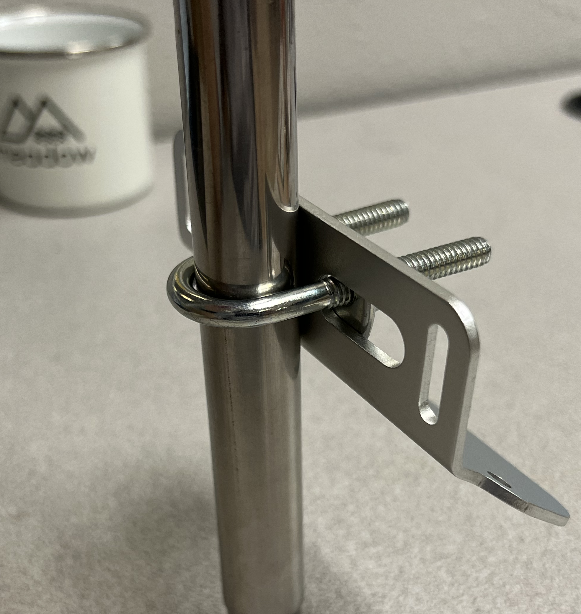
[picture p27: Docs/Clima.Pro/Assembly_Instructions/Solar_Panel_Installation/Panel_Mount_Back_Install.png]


## Install Panel

Using the plastic nuts on the solar panel, attach it to the solar panel bracket mount. Make sure to pull the solar panel power cable through the bracket hole:

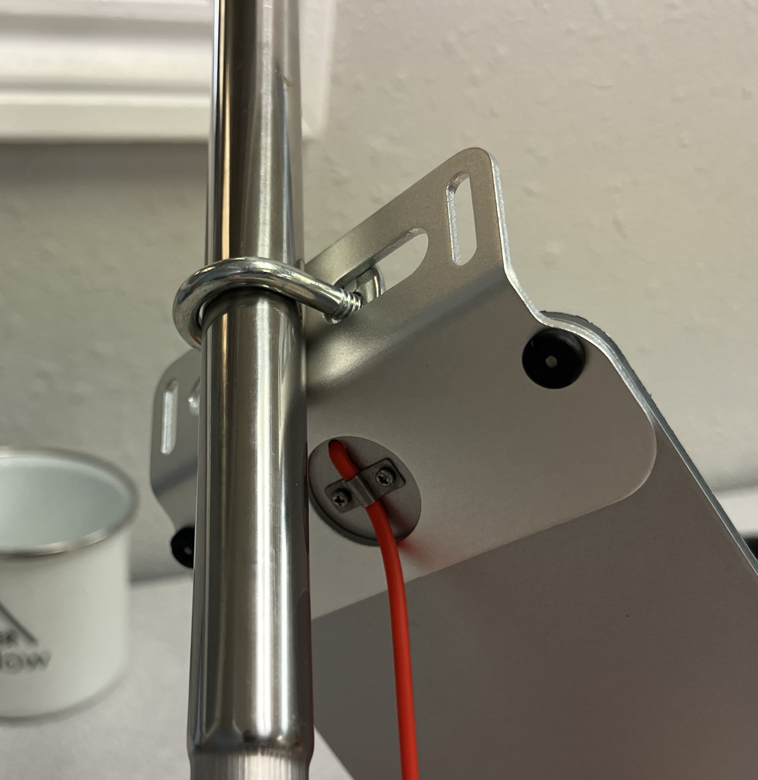
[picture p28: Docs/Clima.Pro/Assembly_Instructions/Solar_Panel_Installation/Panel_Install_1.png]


## [Next - Deploy the Clima App](/Docs/Clima.Pro/Deploy_Instructions/)

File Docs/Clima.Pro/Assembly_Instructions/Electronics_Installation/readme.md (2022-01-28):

# Clima.Pro Electronics Installation

## Install the Antenna Cable and Mount

Unscrew the antenna mount and place it through the hole in the enclosure with the threads up, as shown below. Use the lock-washer on top and the tooth-washer on the bottom:



The antenna mount should fit snuggly, you may need to screw it into place for it to fit.

## Install Battery

Install the 18650 LiIon battery into the holder, paying attention to the polarity. If there is a piece of tape on the battery, remove it:



## Attach Antenna Cable to Meadow

Attach the µFL connector to the Meadow external antenna connector as illustrated below:



## Install the PCB

Using (4) M2x6 screws, install the assembled PCB:



## Install Cover

Using the remaining (4) M2x6 screws, install the cover:



## [Next - Mount the Enclosure](../Enclosure_Mounting/readme.md)

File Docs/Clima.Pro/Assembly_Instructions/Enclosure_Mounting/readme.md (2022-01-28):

# Enclosure Mounting



## [Next - Solar Panel Installation](../Solar_Panel_Installation/readme.md)

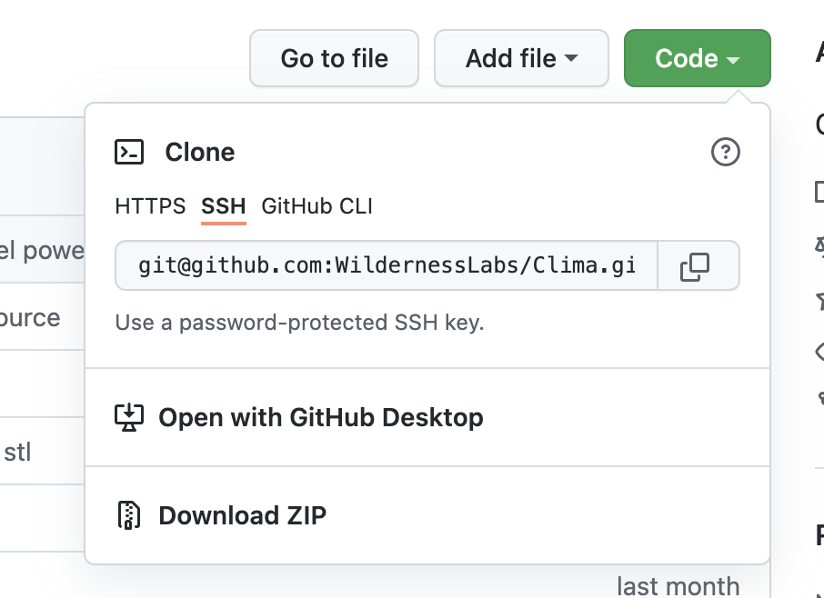
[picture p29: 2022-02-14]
Docs/Clima.Pro/Deploy_Instructions/GitHub_Clone.png

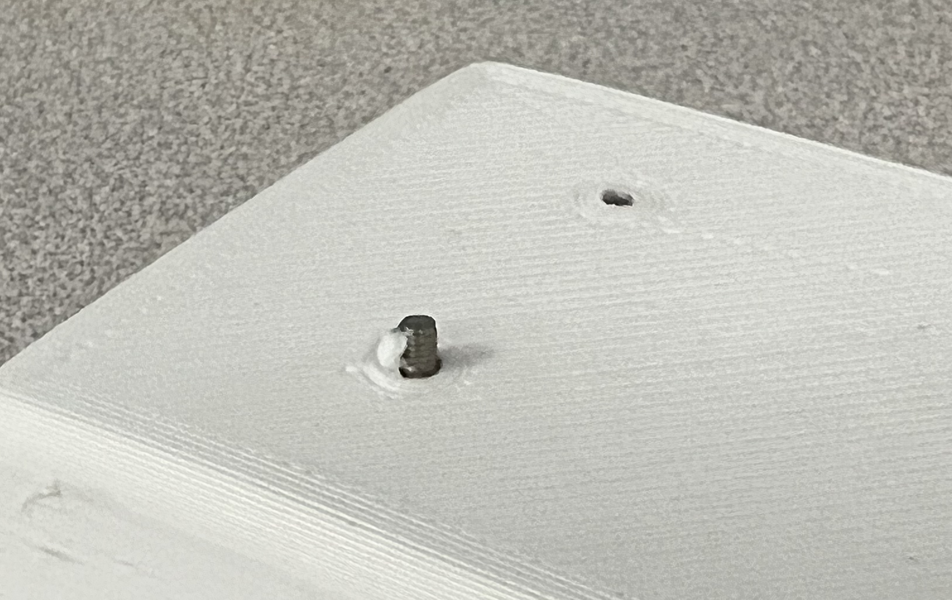
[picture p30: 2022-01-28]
Docs/Clima.Pro/Assembly_Instructions/Enclosure_Assembly/M3_Plunge_Outside.png

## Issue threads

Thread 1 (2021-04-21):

meadow.core not found in local repository (also Meadow.Foundation not found when present)

houstonhaynes, 2021-04-21:
Looks like the Clima project has a dependency on Meadow.Core.

`PS C:\repo\Clima\Source\Clima> dotnet restore Clima.sln
C:\Program Files\dotnet\sdk\5.0.200-preview.21079.7\NuGet.targets(290,5): error MSB3202: The project file "C:\repo\Meadow.Core\source\Meadow.Units\Meadow.Units.csproj" was not found. [C:\repo\Clima\Source\Clima\Clima.sln]`

I'm also seeing this error which I assume is because the restore is failing.

'C:\repo\Meadow.Foundation\Source\Meadow.Foundation.Peripherals\Sensors.Weather.WindVane\Driver\Sensors.Weather.WindVane\Sensors.Weather.WindVane.csproj'. If you are using Visual Studio, this may be because the project is unloaded or not part of the current solution so run a restore from the command-line. Otherwise, the project file may be invalid or missing targets required for restore.	WilderenessLabs.Clima.Meadow.Pro.HardwareDiagnostics	C:\repo\Clima\Source\Clima\WilderenessLabs.Clima.Meadow.Pro.HardwareDiagnostics\WilderenessLabs.Clima.Meadow.Pro.HardwareDiagnostics.csproj'

Is there a place where I can get Meadow.Core? I can't seem to lay my eyes on it here in your public repo.

houstonhaynes, 2021-04-21:
Weird I pulled the local .Core project references and it seemed to use the nuget packages.

Closed 2021-04-21.

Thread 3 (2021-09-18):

Add rain sensor logic

adrianstevens, 2021-09-18:

adrianstevens, 2022-03-08:
Complete - closing issue

Closed 2022-03-08.

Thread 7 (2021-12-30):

Send Data From Meadow to an ASP .NET Server via WiFi Out of Date

JonathanBuchner, 2021-12-30:
For my first practice project I chose the sample project _Send Data From Meadow to an ASP .NET Server via WiFi_ after the Hello, LED project.  The linked directions were not updated and I was unable to follow the directions on the site.  I went to the sample project GitHub and looked at the updates.

Recommendation to add section or badge for _out of date_ or _previous version_ labs to alert users for incorrect lab instructions.  This label is important especially for users doing their first time project.

doingnz, 2025-01-19:
It's really old? Is it still relevant?

@ctacke should this issue be moved to the samples repository as it's not Clima specific.

doingnz, 2025-02-15:
@jorgedevs, @bryancostanich is this issue for December 2021 still relevant? should it be closed or moved to samples? Is it Clima specific or more general to all Meadow samples?

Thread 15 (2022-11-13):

Add RGB LED to Clima Pro's PCB as a status indicator

jorgedevs, 2022-11-13:
It's hard to tell if Meadow App is running properly once deployed out in the field with no visible indication that the app is running, or the system is turned on.

bryancostanich, 2023-08-28:
Added in v3.

Closed 2023-08-28.

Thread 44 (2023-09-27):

[Clima.HackKit] Fritzing diagram LM35 error

patridge, 2023-09-27:
https://github.com/WildernessLabs/Clima/blob/main/Image_Assets/Clima_Fritzing_Diagram.png

The LM35 is off-by-one and appears to be flipped front-to-back.

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

If I am reading this [TI datasheet](https://www.ti.com/lit/ds/symlink/lm35.pdf) correctly, the front (flat) side has the left pin as GND.

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

That would mean the component should be flipped over and moved one pin down.

NevynUK, 2023-10-02:
I don't think is flipped, off by one, yes; flipped, no.

jorgedevs, 2023-11-27:
Good catch and diagram corrected, available on `develop` branch.

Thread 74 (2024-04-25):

Hardware/Feature Requests for vNext (v5?)

ctacke, 2024-04-25:
For the next version of Clima, I propose the following features:

1) A fan relay.
We're using a temp sensor of the board, and having that in the enclosure that could be in the sun could yield data that isn't great.  Adding a small 30mm case fan could help.
2) Screw terminals for an external thermistor
For the reason above, the option of an external wired thermistor would be good
3) A light sensor and light pipe
Being able to determine if we're in daylight/direct sun may also assist with #1 above
4) A battery-backed RTC
When the device boots it may or may not have a network connection.  If it starts logging data before an NTP time comes in, we need to do math to back-correct those data points, which is not fun.
5) Remove the GPS
It's used for locating the device, but typically there are fixed-mount so it seems like a lot of BOM cost for a one-time data point that could be achieved in another way
5) 4-pin header for an SSD1306 I2C display
The ability to optionally plug in a small I2C display is extremely helpful for development and testing.

jbeenes, 2024-05-07:
7. Also maybe add the ability to use some free pins to connect some custom hardware. Like the Qwiic I2C connector on the v3 already can be used for (I presume).

doingnz, 2024-05-31:
1. Solar charger should feature MPPT to get optimum power from the solar panel.
2. Battery management should be integrated solution taking power from solar, usb or battery and delivering regulated power to CCM to optimise run time and safe transitions between the power sources, charging battery when surplus energy is available.
3. Probably need two batteries to store enough charge and to make the battery management circuit easier.
4. CPU supervisor to manage RESET in place of simplistic RC
5. Through holes or provision on PCB to mount reset and boot buttons mounted on the case and externally accessible without removing the cover.
6. Option to fit a power switch in-line with battery. Maybe two through-holes joined with a track on the PCB to make default always ON. To fit the power switch, cut the track and solder wire or connector into the holes. This is needed as there are times reset is not enough and power must be removed from the Meadow to properly reset (maybe #4 fixes this issue in longer term?).

doingnz, 2024-05-31:
Switch to ESP32-C5 for Dual-Band Wi-Fi 6

ctacke, 2025-01-17:
Move anemometer input to a pin with a hardware timer to enable hardware counting

doingnz, 2025-01-17:
Consider through hole RGB led to have option to mount the LED in the case to make it visible when Clima is outside. Potentially could use a light pipe for the SMB RGB, but that limits the location of the LED on the external case which limits overall assembly to ensure it's visible when the Clima is assembled and mounted on a pole. In either case, consider placement relative to a light sensor if that is included in the next design. e.g. light sensor on top of the case and LED at the bottom.

doingnz, 2025-01-19:
Consider what if any hardware is needed to develop a mechanism to configure an individual Clima to use a specific local wifi network and/or configure other settings. i.e. mechanism to have single software image that can be loaded into many Clima devices and then subsequently configure them with per device settings.

e.g. Do we need a user button or 2 that can detect in software short press, long pressure, etc. Clima app could interpret the key presses to run a local access point or Bluetooth mode to permit a mobile app to connect to the local Clima and exchange credentials and configure the device.

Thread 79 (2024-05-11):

Wind direction is uncalibrated

ctacke, 2024-05-11:
The wind direction from the wind vane reports a 0-360 value, presumably from some fixed point on the hardware.  It bears no relation to the actual installed orientation to true north, so the reported direction is only going to be right by accident of install.  The app needs to support a calibration offset and there needs to be some way to set/update that offset after the hardware is installed.

doingnz, 2025-01-18:
A potential solution to consider is adding the following to SensorController.cs

```
    /// <summary>
    /// 0 to 360 degree offset to true north.
    /// After install of clima, point wind vane at true north and record WindDirection.
    /// Configure Clima.TrueNorth setting in app.config.yaml
    /// </summary>
    public Azimuth OffsetToNorth { get; private set; } = new Azimuth(0.0);

```

Modify the update method to subtract the offset
```
    private void WindvaneUpdated(object sender, IChangeResult<Azimuth> e)
    {
        Azimuth newAzimuth = e.New - OffsetToNorth;
        windVaneBuffer.Append(newAzimuth);

        Azimuth mean = windVaneBuffer.Mean();

        lock (latestData)
        {
            latestData.WindDirection = mean;
        }

        Resolver.Log.InfoIf(LogSensorData, $"Wind Vane:       {e.New} -> {newAzimuth} (mean: {mean.DecimalDegrees})");
    }
```

Add a setting to app.config.yaml
```
# Settings for Clima
Clima:
  TrueNorth: 270.0
```

and try read this setting in the constructor.

```
    public SensorController(IClimaHardware clima)
    {
        latestData = new SensorData();
        this.clima = clima;

        if (Resolver.App.Settings.TryGetValue("Clima.TrueNorth", out string trueNorthString))
        {
            if (Double.TryParse(trueNorthString, out double trueNorth))
            {
                OffsetToNorth = new Azimuth(trueNorth);
            }
        }
    }
```

If the setting is not configured, the reported values are not changed ortherwise the buffered average values are calculated with the offset removed.

Example output when log enabled

```
[application] Wind Vane:       270 -> 0 (mean: 0)
```

Let me know if you like this approach and I can submit a PR.

doingnz, 2025-02-15:
@ctacke When do issues get closed? When the functionality is merged into develop or only when merged into main?

doingnz, 2025-05-08:
@ctacke can this issue be closed?

Closed 2025-08-04.

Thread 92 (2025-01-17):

Move anemometer to an input with a timer

ctacke, 2025-01-17:
OS version 2.0.x has hardware timing capabilities.  Offloading wind speed sensor counting to that will help the app run better.  Clima 4.x has it on `PA5` which doesn't have a timer, therefore doesn't support hardware counting.  Next rev should move it to one that does.

doingnz, 2025-05-08:
Ideally select a timer that can run in low power mode without the CPU being active.

The OS needs to be extended to support the timer in "COUNTER" mode to ensure low wind speeds can be measured. The current 2.x FW has a 1 Hz low frequency limitation which limits measurement of wind speed below 2.4 km/hr,

Using a counter would enable measurement of a low number of counts over a longer sampling time to measure lower wind speeds. It would also remove the requirement for CPU work to measure the frequency, just read the counter and calc delta since last counter read.

bryancostanich, 2025-08-05:
moved to `PA3`, which is a 32-bit timer in v5.

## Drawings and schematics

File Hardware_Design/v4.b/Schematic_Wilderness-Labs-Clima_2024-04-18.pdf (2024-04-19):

10, 12, 13

## Reserved Interrupts

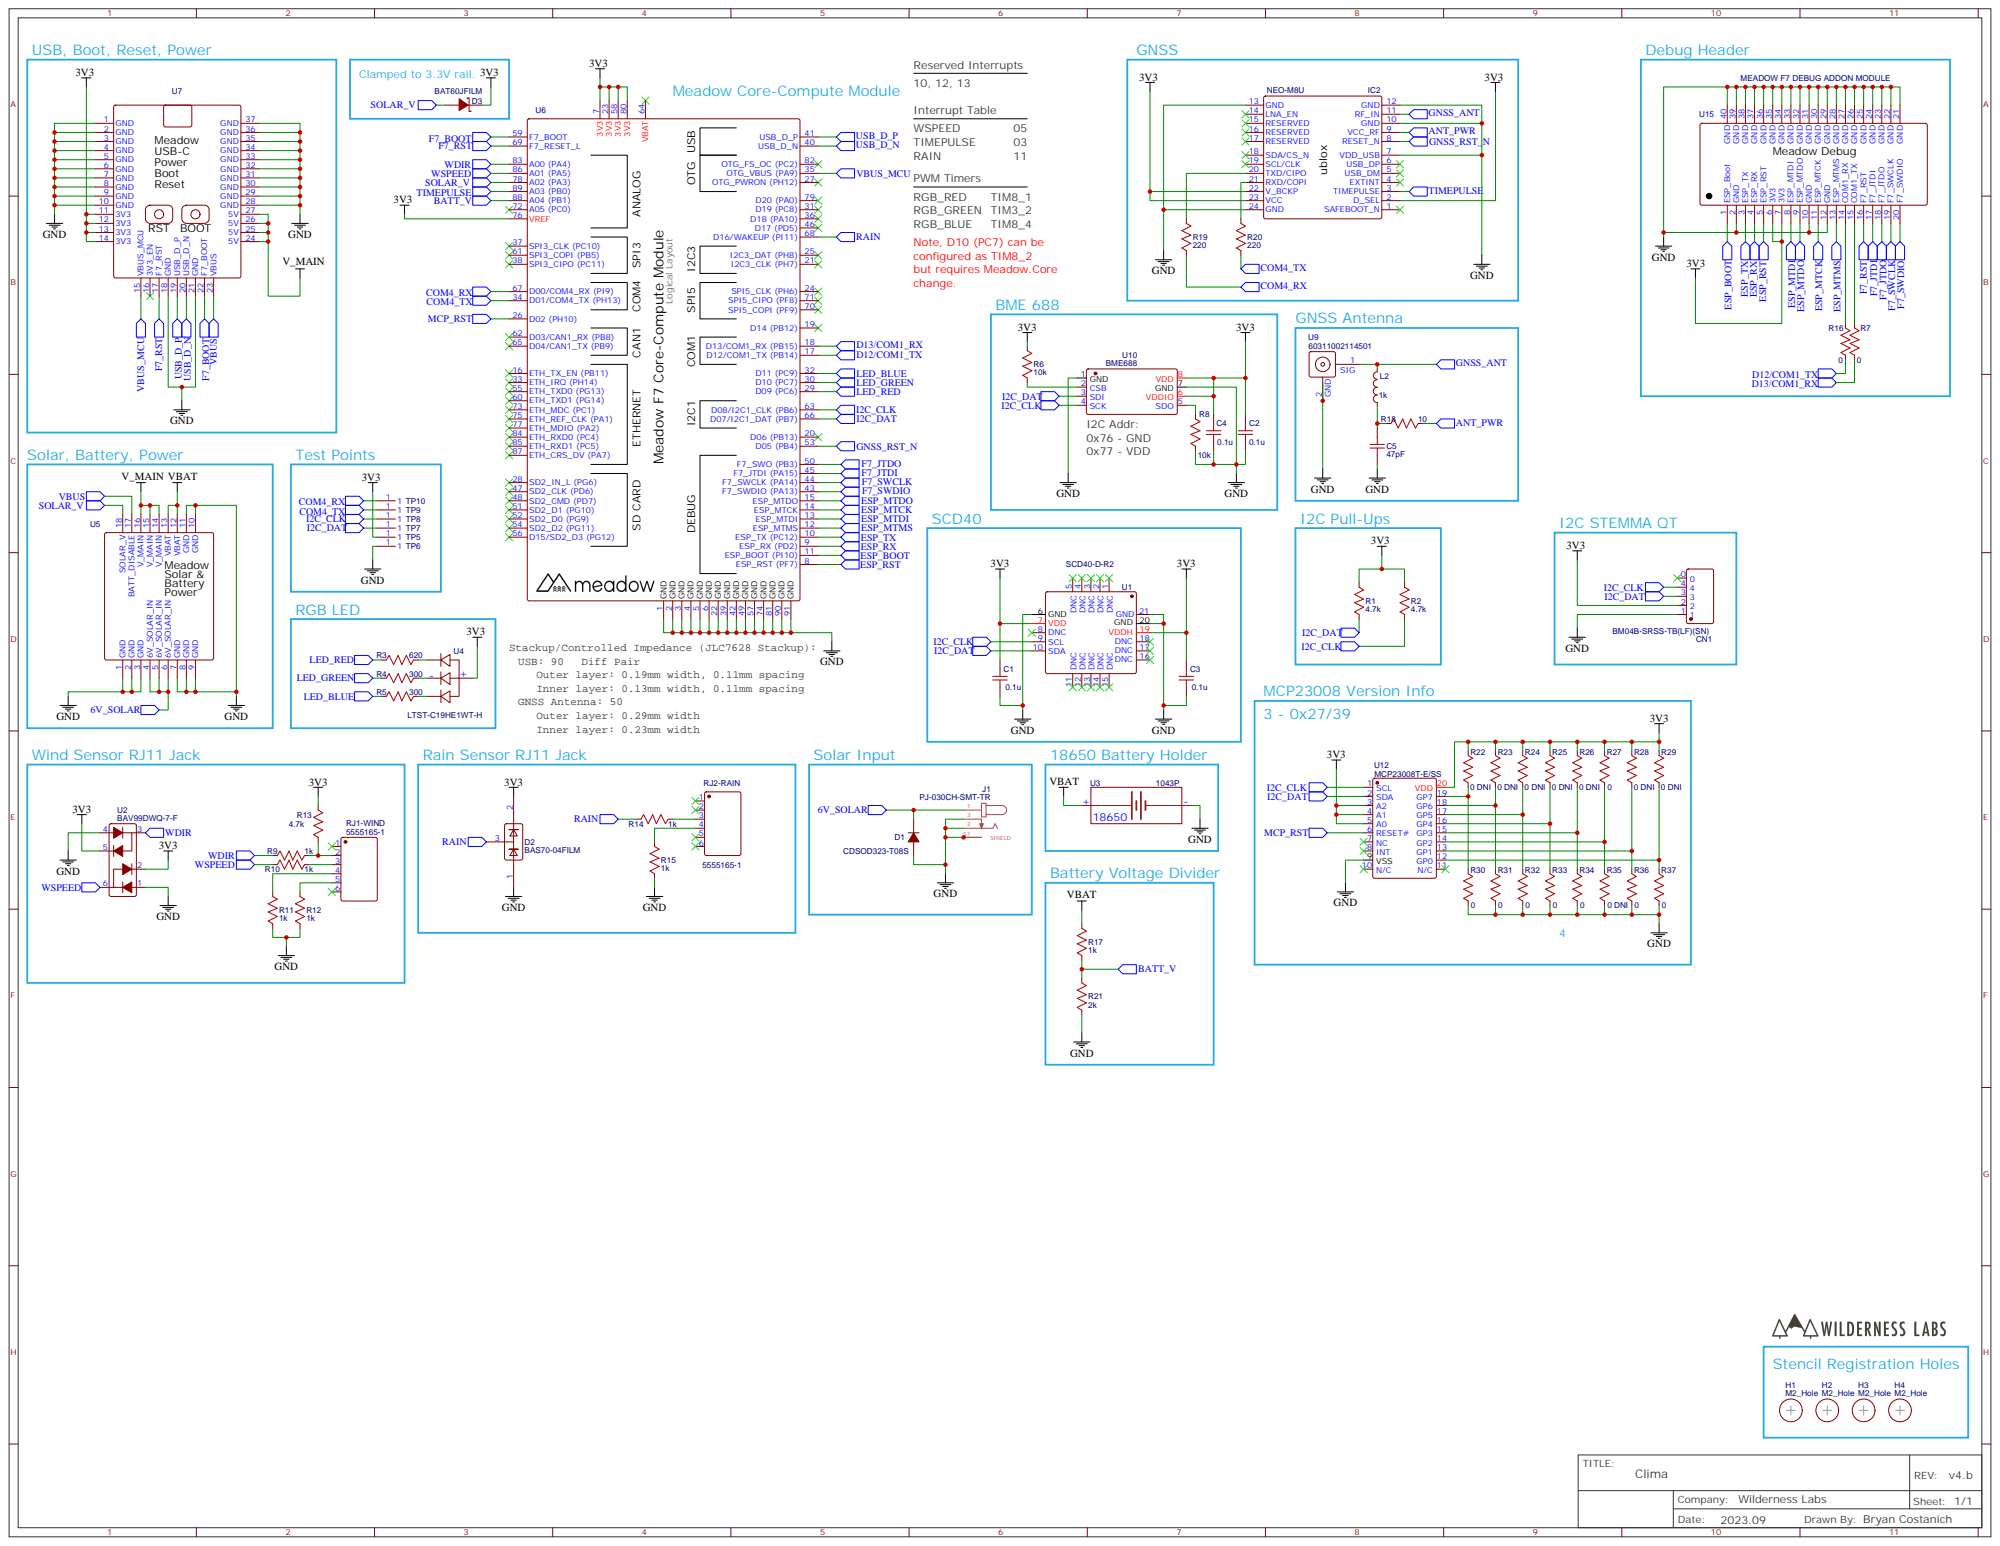
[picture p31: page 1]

USB, Boot, Reset, Power USB_D_P USB_D_N F⁷_BOOT F⁷_RST

MEADOW F7 DEBUG ADDON MODULE

Meadow Core-Compute Module

5V 24 5V 25 5V 26 5V 27 GND 28 GND 29 GND 30 GND 31 GND 32 GND 33 GND 34 GND 35 GND 36 GND 37

F7_SWDIO 20 GND 21 GND 22 GND 23 GND 24 GND 25 GND 26 GND 27 GND 28 GND 29 GND 30 GND 31 GND 32 GND 33 GND 34 GND 35 GND 36 GND 37 GND 38 GND 39 GND 40

Meadow F7 Core-Compute Module

Note, D10 (PC7) can be
configured as TIM8_2
but requires Meadow.Core
change.

9 GND 10 GND 11 VBAT 12 VBAT 13 V_MAIN 14 V_MAIN 15 V_MAIN 16 BATT_DISABLE 17 SOLAR_V 18

BM04B-SRSS-TB(LF)(SN)

Stackup/Controlled Impedance (JLC7628 Stackup):
Outer layer: 0.19mm width, 0.11mm spacing
Inner layer: 0.13mm width, 0.11mm spacing
GNSS Antenna: 50
Outer layer: 0.29mm width
Inner layer: 0.23mm width

Drawn By: Bryan Costanich

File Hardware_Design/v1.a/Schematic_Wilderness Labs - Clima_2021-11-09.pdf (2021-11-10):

## F7 Micro

# Solar Input

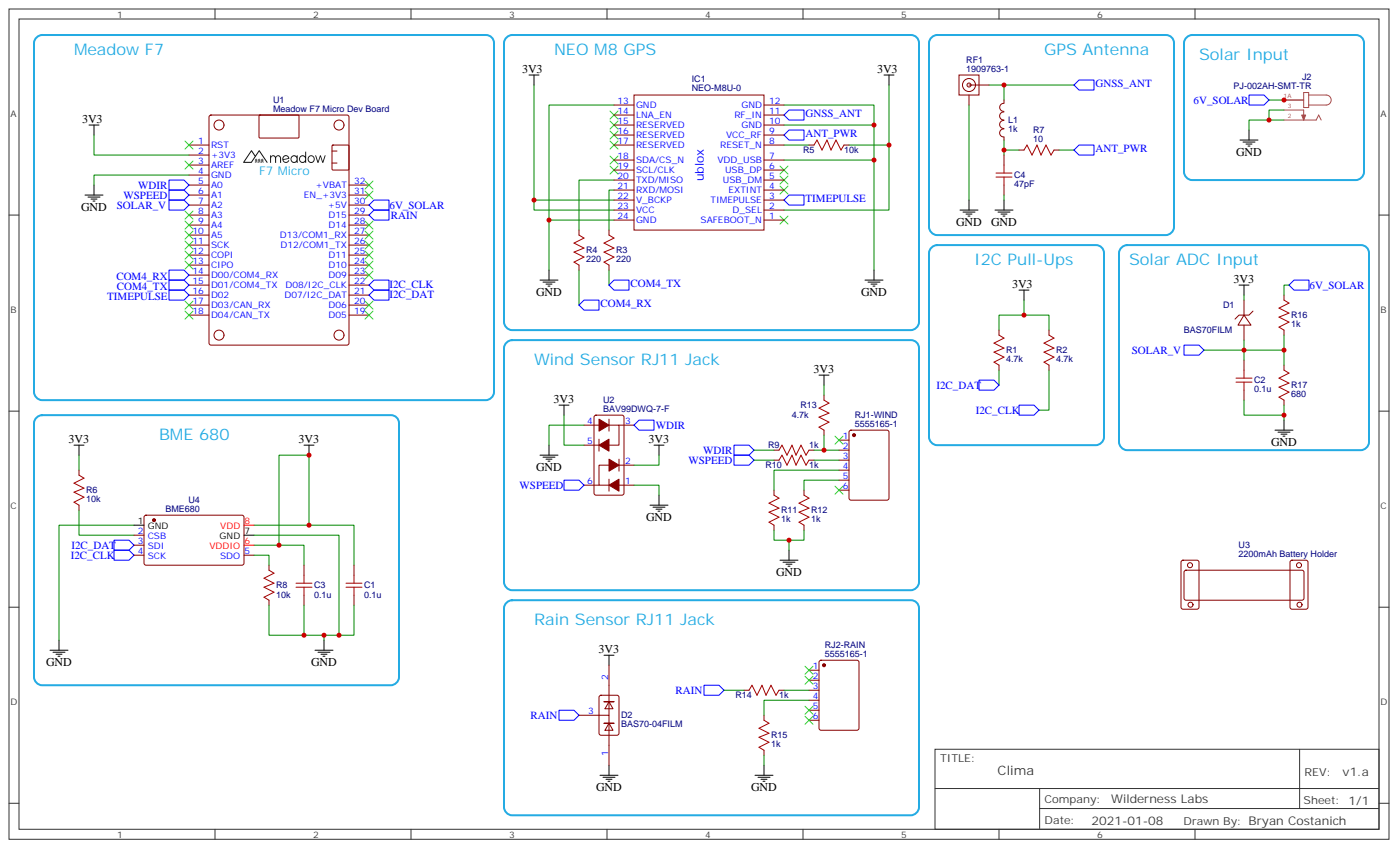
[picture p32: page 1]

Meadow F7 Micro Dev Board

Drawn By: Bryan Costanich

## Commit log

2020-09-25 Initial cut of apps
2021-02-10 Initial pro PCB version hardware diagnostics
2021-02-12 first draft of anemometer driver
2021-02-14 bunch of working units and driver stuff
2021-08-25 Added industrial design files.
    [Clima.Pro Enclosure.f3d, Clima_Clamp.f3d, Enclosure_Bottom.stl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]
2021-09-18 Remove tight coupling from db manager and climate monitor agent
2021-11-10 added hardware design source
    [BOM_Wilderness Labs - Clima_2021-11-09.csv]
2021-12-16 Updated enclosure design to accommodate new pcb size
    [Clima.Pro Enclosure.f3d, Clima_Enclosure_Bottom.stl, Clima_Enclosure_Top.stl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]
2021-12-16 fixed gasket line to go all the way around on lid
    [Clima.Pro Enclosure.f3d, Clima_Enclosure_Top.stl]
2022-01-09 Update Clima HackKit diagram and image
    [Clima.HackKit.fzz]
2022-01-10 Made enclosure bottom m2 heat set holes slightly smaller for better adhesion
    [Clima.Pro Enclosure.f3d, Clima_Enclosure_Bottom.stl]
2022-01-10 Added BoM and some new docs
2022-01-10 assembly stubs
2022-01-10 printing info
2022-01-10 added image, deleted old stl
    [Clima_Enclosure_Bottom.stl]
2022-01-22 Update diagnostics app to use Bme680 and SwitchingRainSensor
2022-01-24 [MeadowClimaProKit.Tests] Add Bme68x and SwitchingRainGauge packages
2022-01-25 [MeadowClimaHackKit] Update to store temperature on a sqlite database
2022-01-28 bunch of assembly doc drafts
2022-01-28 Update expected power/sleep APIs
2022-02-02 [Readme] Assembly sensor instructions
2022-02-07 [Readme] Assembly instructions
2022-02-11 [MeadowClimaHackKit] - Add LedController
2022-02-12 Added final photos to enclosure instructs
2022-02-12 solar mount instruct
2022-02-12 Slight clarity on solar panel power cable.
2022-02-13 [MeadowClimaProKit] Add SwitchingRainGauge to the ClimateMonitorAgent and adjust data model
2022-02-18 Fix skip enclosure assembly link Enclosure_Assembly/readme.md
2022-02-22 [MeadowClimaProKit] Fix SPI Addresses for BME280
2022-05-08 updated info on solar charging
2022-06-10 Added note about new solar circuit
2022-07-02 Updated enclosure with new height to accommodate the new solar charger circuit
    [Clima.Pro Enclosure.f3d, Clima_Enclosure_Bottom.stl]
2022-08-08 add solar voltage check
    Updated the diagnostic app to check the solar voltage input.
    Also fixed the namespace of the app.
    Note: this builds but i can't test right now, because i can't deploy the OS.
2022-10-18 added note about boards shipping
2022-10-25 Switch to NuGet packages
2022-11-13 Change order of Clima Pro assembly
2022-11-22 Remove test button.
2022-11-22 Disable BLE button for Windows
2022-11-22 Updated enclosure to fit the new board
    [Clima.Pro Enclosure.f3d, Clima_Enclosure_Bottom.stl]
2023-05-05 Added RgbLed support + pin fixes
2023-07-04 Folder reorg and rename project samples
2023-07-05 Update Clima HackKit sample with Companion app
2023-07-05 Rename additional samples
2023-10-10 Added v3 enclosure files
    [CL_Enclosure_Bottom.stl, CL_Enclosure_Top.stl, Clima v3 Enclosure.f3z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]
2023-10-11 adding correct lid
    [CL_Enclosure_Top.stl]
2023-11-10 Fix Fritzing diagram
    [Clima.HackKit.fzz]
2023-11-14 Read battery volage and clean up logged text and comments
    Read and output the battery voltage on V3 Clima. Fix Log text. Set V2 & V3 interface comments to have same text.
2023-12-08 Init RGB LED first, remove unused commented code
    It is necessary to init PWM Timer before other I/O to avoid a bug in Nuttx described in DeviceChannelmanager.cs
2023-12-09 change reference voltage to account for ideal resistor divider networks at analogue inputs.
2023-12-20 add using Meadow to reference the correct Color class
    Changes in Meadow assemblies required adding using Meadow to Cliam projects to permit build to succeed.
2023-12-23 Ensure values used to calculate scale factors are doubles
    Add '.0' to constants to ensure compiler uses doubles when calculating scale values for voltage reference.
2024-02-03 Refactor for sensor service
2024-02-03 Add Qwiic connector to hardware conrtact
2024-02-03 Add connector scaffolding
2024-02-03 Add v4 hardware class with connector
2024-02-03 Register weather sensors with sensor service
2024-02-04 Check version mcp to switch between v3 and v4 hardware
2024-04-18 added v4 schematic and mechanicals
    [Clima4_Enclosure_Bottom.stl, Clima4_Enclosure_Top.stl]
2024-04-19 More clean-up and refactoing of power and sensor telemetry
2024-05-01 added STLs for flat-mount cleat
    [clima4-cleat-f.stl, clima4-cleat-m.stl]
2024-05-15 added optional light sensor
2024-05-20 attempting to improve power consumption
2024-06-05 added error handling. adjusted sensor report time intervals
2024-06-09 record device name and position when position data arrives
2024-06-28 Additional Samples moved to Meadow.Samples
2025-01-13 Remove the light sensor (not part of Clima)
2025-01-13 More light sensor cleanup
2025-01-17 do not start network automatically
    code flow needs the connected network event which may not be raised if the wifi automatically connects.
2025-01-17 Change Power Controller to use return Task.FromResult(...)
    This change appears to make it easier to connect to the wifi network in Clima. (previous code appears to block esp events during startup)
2025-02-04 Optimise Start of LocationController to after Network is connected
    GNSS generates a lot of UART data that trriggers many interrupts that slow the logon to wifi and MQTT connect to the Cloud. Starting the LocationController after connecting to Meadow Cloud makes over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
2025-02-05 Add OffsetToNorth to app.config.yaml as calibration for WindDirection true north
    This offset will be subtracted and defines direction of wind vane's 0 Degrees.
2025-02-05 calculate average wind speed
    save 12 samples of wind speed and calculate average.
2025-02-11 add missing humidity to SensoreData Copy() and Clear() methods
2025-02-15 Remove UdpLogger when network disconects
    Add/Remove UdpLogger when network connects/disconnects. Move hardcoded SSID, PASSWORD and PORT to private propertes to make it easier to maintain these currently hardcoded values. In the future makes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
2025-05-04 changed temp sensor itnerface
2025-07-28 Fix enclosure files link
